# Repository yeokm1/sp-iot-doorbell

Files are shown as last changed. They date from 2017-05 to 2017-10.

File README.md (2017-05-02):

# SP IoT doorbell

An IoT doorbell at Singapore Power's Digital Tech office that will take a picture of a visitor and notify a Slack channel when the button pressed. The operating system used is Arch Linux ARM and the code is in Python 3.

## Pictures and Demo video

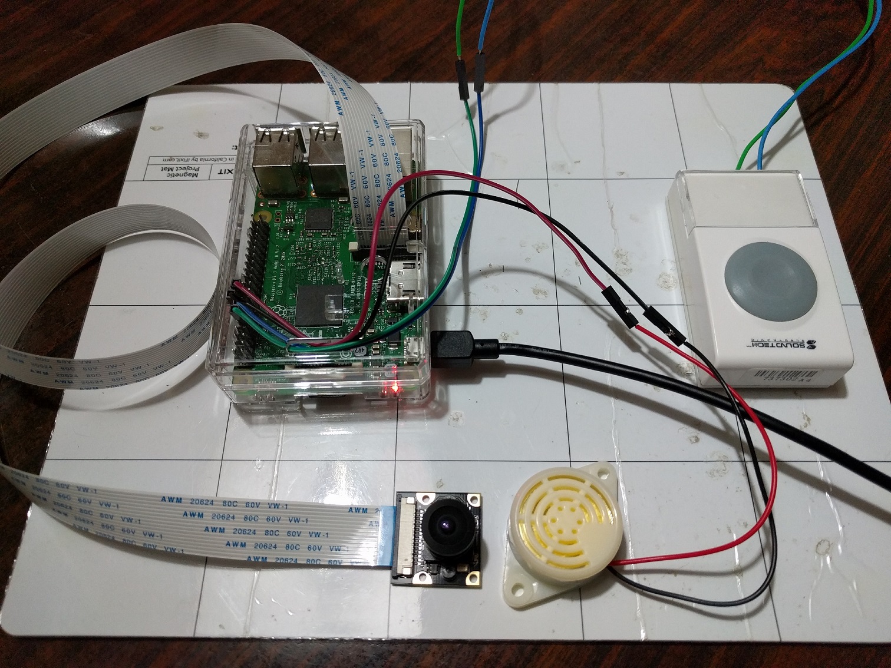
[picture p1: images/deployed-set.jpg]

This is the set that is actually deployed with a proper button and wide-angle camera.

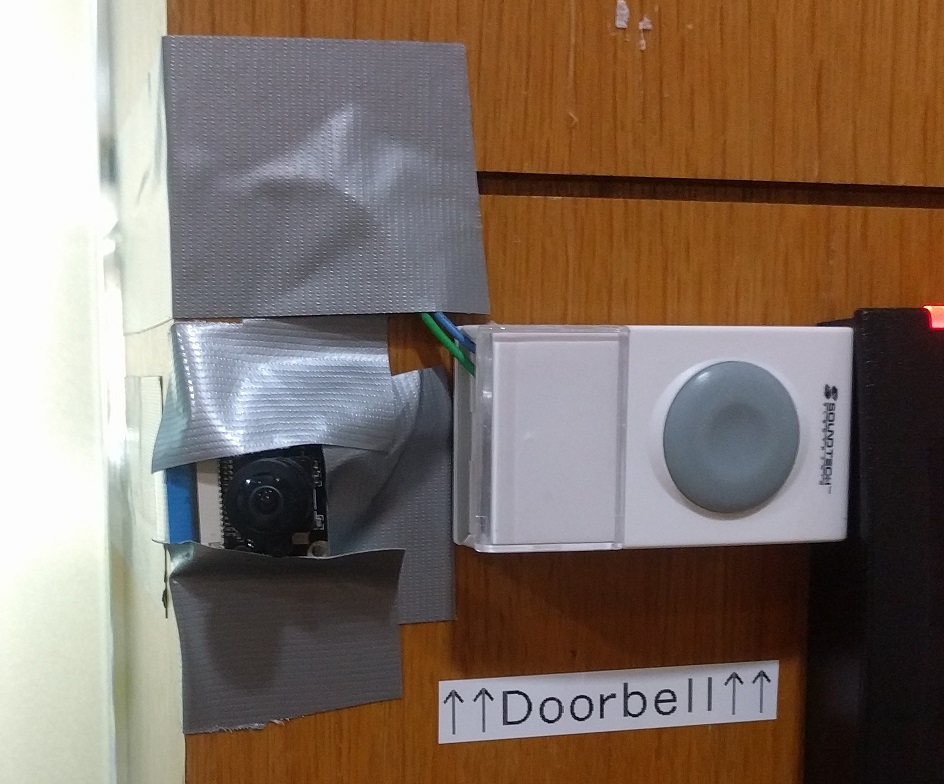
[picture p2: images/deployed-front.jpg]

The camera and button are placed in line to make sure they are associated to be together. Button is modified from an actual doorbell.

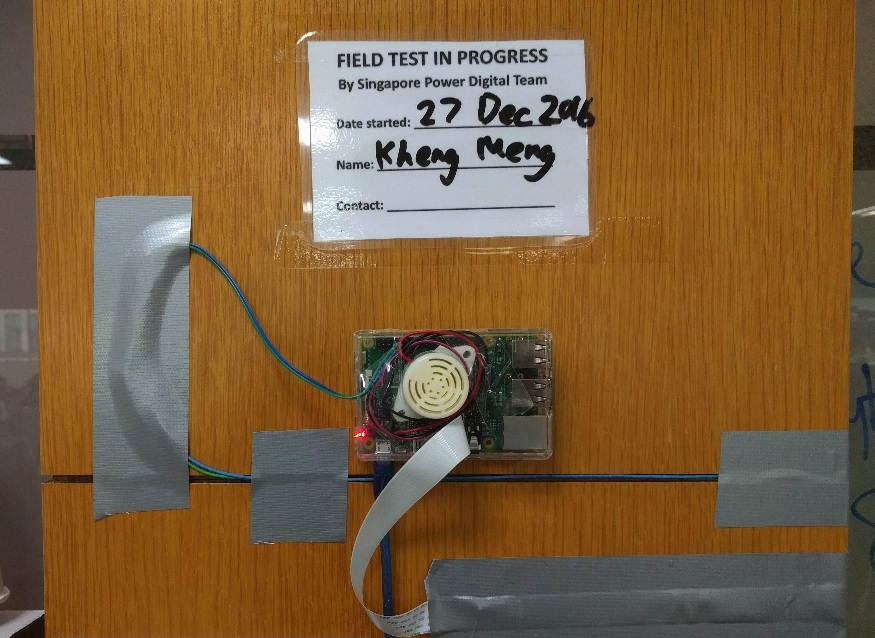
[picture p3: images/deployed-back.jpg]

The camera and button are connected to a Raspberry Pi at the back.

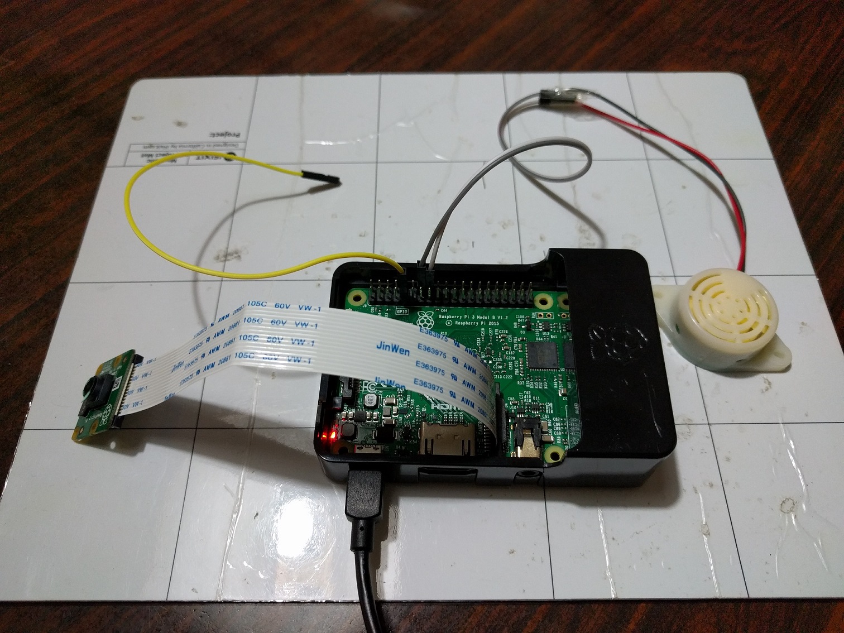
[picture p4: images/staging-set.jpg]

This is used for testing purposes before moving the SD card image to the deployed set. The button is simulated by shorting the pins. Camera is the official [8MP camera board v2](https://sg.element14.com/raspberry-pi/rpi-8mp-camera-board/raspberry-pi-camera-board-v2/dp/2510728).

(http://www.youtube.com/watch?v=MGRNmj3iRuI)

## Behaviour workflow

1. On bootup, the `iot-doorbell.service` in started which in turn launches the `iot-doorbell-startup.sh` shell script. The shell script starts the `bell-camera.py` python code.
2. One beep is output to indicate that the program is started.
3. The program will test connectivity to `http://slack.com` by repeatedly hitting it at a rate of 1 attempt/second beeping each time it does so.
4. If 20 failed attempts has been made, the program will stop trying and output only 1 beep to indicate the failure. It will then continue in just a dumb doorbell mode. If connection is achieved later, the pictures will also be sent.
5. If connectivity to Slack is successful, the program will output 2 beeps and send a boot success message to Slack.
6. Whenever the button is pressed, the program will start a thread to send one text-only message first so the Slack channel can be alerted quickly. The image is then taken and uploaded in a second message which will take slightly longer.
7. I have set the minimum interval between messages sending to be 10 seconds to prevent channel flooding from continuous pressing. The bell however will continue to ring as long as the button is pressed.

## Schematic

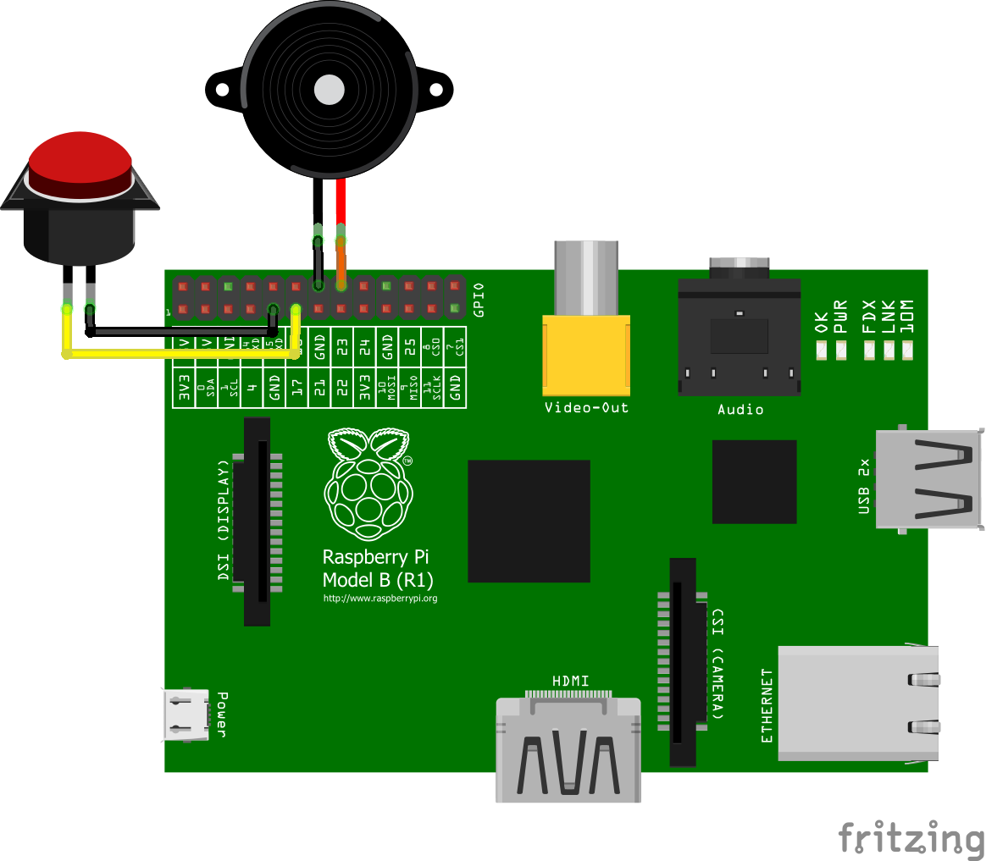
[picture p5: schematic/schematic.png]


A Fritzing drawing indicating the connection between the components to the Raspberry Pi 3. The picture depicted is that of the first Pi B+ which has the exact same pinout as the Pi 3 for the first few pins.

A wide-angle camera is connected to the CSI connector.

## Parts required
1. Raspberry Pi 3
2. 8GB or larger SD card
3. [Piezo Buzzer 3-20VDC Continuous Tone](http://www.sgbotic.com/index.php?dispatch=products.view&product_id=1926)
4. [Raspberry Pi Wide Angle Camera Module](https://www.seeedstudio.com/Raspberry-Pi-Wide-Angle-Camera-Module-p-2774.html)
5. [70cm Camera Flex cable](http://www.sgbotic.com/index.php?dispatch=products.view&product_id=2258)
6. [Raspberry Pi clear case](http://sg.element14.com/multicomp/83-17540/enclosure-raspberry-pi-3-2-b-clear/dp/2674868)
7. 2A USB Power Adapter
8. microUSB cable for power
9. Some random doorbell button
10. USB-TTL cable for configuration

## Setting up the Raspberry Pi from scratch

1) Set up the Arch Linux ARM on an SD card by following the [official instructions](https://archlinuxarm.org/platforms/armv8/broadcom/raspberry-pi-3).

2) Before removing the SD card from the computer, access the `boot` partition. Open `config.txt`. Add the following into the file. First 3 lines enable the camera. Last line enables the console over the UART pins.

```
gpu_mem=128
start_file=start_x.elf
fixup_file=fixup_x.dat
enable_uart=1
```
3) Power on the RPi and convert the file system to read-only if needed by following my [gist](https://gist.github.com/yeokm1/8b0ffc03e622ce011010). You don't have to enable root over SSH as we will disable SSH at the end of this anyway.

4) Connect an Ethernet cable with internet connection. Enter the root account via the USB-UART and run the following commands

```bash
#Install all dependencies
pacman -Syu python python-pip wget base-devel yajl git cronie
pip install requests

#Let alarm user control gpio pins without being root
groupadd -f -r gpio
usermod -G gpio alarm
vi /etc/udev/rules.d/99-gpio.rules

#Add the following to the 99-gpio-rules file
SUBSYSTEM=="bcm2835-gpiomem", KERNEL=="gpiomem", GROUP="gpio", MODE="0660"
SUBSYSTEM=="gpio", KERNEL=="gpiochip*", ACTION=="add", PROGRAM="/bin/sh -c 'chown root:gpio /sys/class/gpio/export /sys/class/gpio/unexport ; chmod 220 /sys/class/gpio/export /sys/class/gpio/unexport'"
SUBSYSTEM=="gpio", KERNEL=="gpio*", ACTION=="add", PROGRAM="/bin/sh -c 'chown root:gpio /sys%p/active_low /sys%p/direction /sys%p/edge /sys%p/value ; chmod 660 /sys%p/active_low /sys%p/direction /sys%p/edge /sys%p/value'"
#end of adding
```
5) Switch over to the alarm user. This user account will be used to run non-privileged stuff including the python program.

```bash
su alarm
cd ~
git clone https://github.com/yeokm1/sp-iot-doorbell.git
cd sp-iot-doorbell

#chmod in case you transfer the file in without executable permissions
chmod +x iot-doorbell-startup.sh
su -c "cp iot-doorbell.service /etc/systemd/system/"

#Install yaourt so as to prepare to install the GPIO package from AUR
cd ~
git clone https://aur.archlinux.org/package-query.git
cd package-query
makepkg -s
su -c "pacman -U package-query-1.8-2-armv7h.pkg.tar.xz"

cd ..

git clone https://aur.archlinux.org/yaourt.git
cd yaourt
makepkg -s
su -c "pacman -U yaourt-1.8.1-1-any.pkg.tar.xz"

yaourt -S python-raspberry-gpio

#1. Enter "1" to install the only package if asked
#2. Give alarm (default "alarm") and root password (default "root") when asked
#3. Do NOT edit PKGBUILD or anything else when they say "Unsupported Package" or similar warnings. Press "N".
#4. Answer Yes to install any requested dependencies or building

#Clear command history
history -cw
exit
```

6) You should be back to the root account.

```bash
#Restart the device every Monday at 0700
crontab -e
00 7   *   *   1    /usr/bin/reboot
systemctl enable cronie.service

#Enable the service so the program will start on boot
systemctl enable iot-doorbell.service

#Disable SSH for security reasons
systemctl disable sshd
```

7) Configure Wifi settings (Optional)

```bash
cp /etc/netctl/examples/wireless-wpa /etc/netctl/.
nano /etc/netctl/wireless-wpa
#Adjust settings to match your network

#This is to test your profile. If you are not using SSH, you should unplug the Ethernet cable now to test.
netctl start wireless-wpa
#Take effect on every boot
netctl enable wireless-wpa
```

8) Change default user passwords

```bash
passwd root

passwd alarm
```

9) Clear command history and reboot

```bash
#Clear command history
history -cw

reboot
```

## References

1. [Check server availability in Python](http://stackoverflow.com/questions/3764291/checking-network-connection)
2. [Post requests in Python](http://stackoverflow.com/questions/37283111/cannot-post-images-to-slack-channel-via-web-hooks-utilizing-python-requests)
3. [Use GPIO without being root](https://arcanesciencelab.wordpress.com/2016/03/31/running-rpi3-applications-that-use-gpio-without-being-root/)

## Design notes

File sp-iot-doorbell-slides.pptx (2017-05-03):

## SP Office Gadget: IoT Doorbell

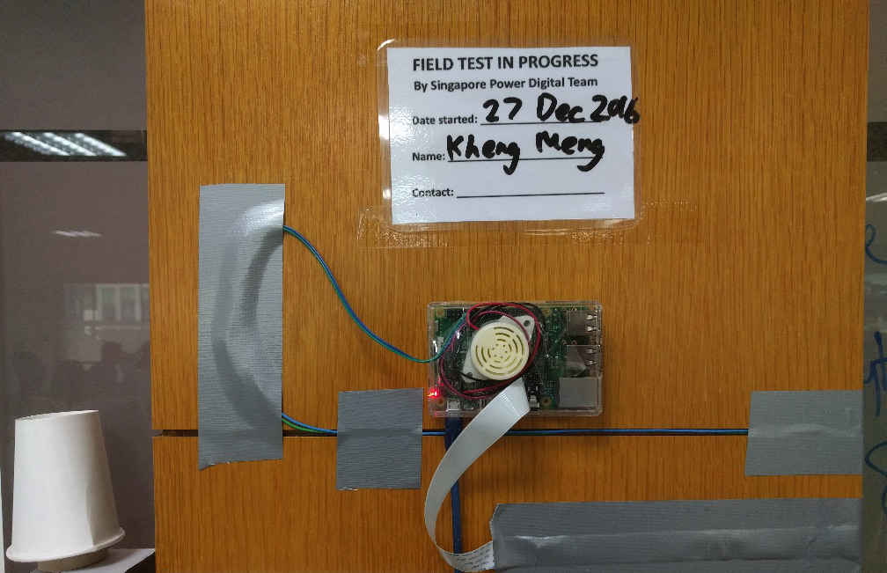
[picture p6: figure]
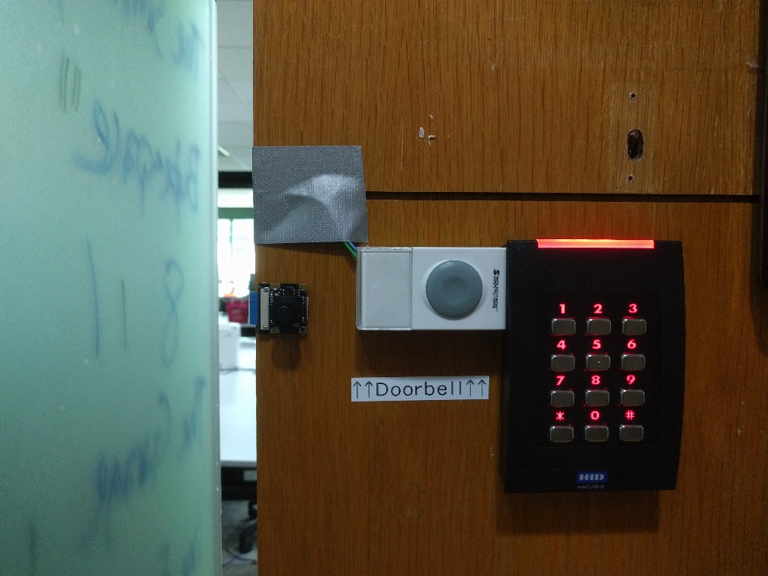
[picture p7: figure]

By: Yeo Kheng Meng (yeokm1@gmail.com)
https://github.com/yeokm1/sp-iot-doorbell

Hackware v3.0 (3 May 2017)
SP Digital Tech Talk (29 Dec 2016)

## Problem?

- My office needs a doorbell
- Solution: An overengineered IoT doorbell

## Solution Outline

1. Rings when button is pressed
2. Informs Slack channel via Wifi connection
3. Takes photo and uploads to Slack
4. File system resilience against improper shutdown

## Demo video

- https://www.youtube.com/watch?v=MGRNmj3iRuI

## MVP Dev Set

- Raspberry Pi 3
- 8MP RPi camera v2
  - Sony IMX219
  - Connected via Camera Serial Interface connector
- 3V-20V DC Continuous Buzzer
- Wire simulated as a button


## The button

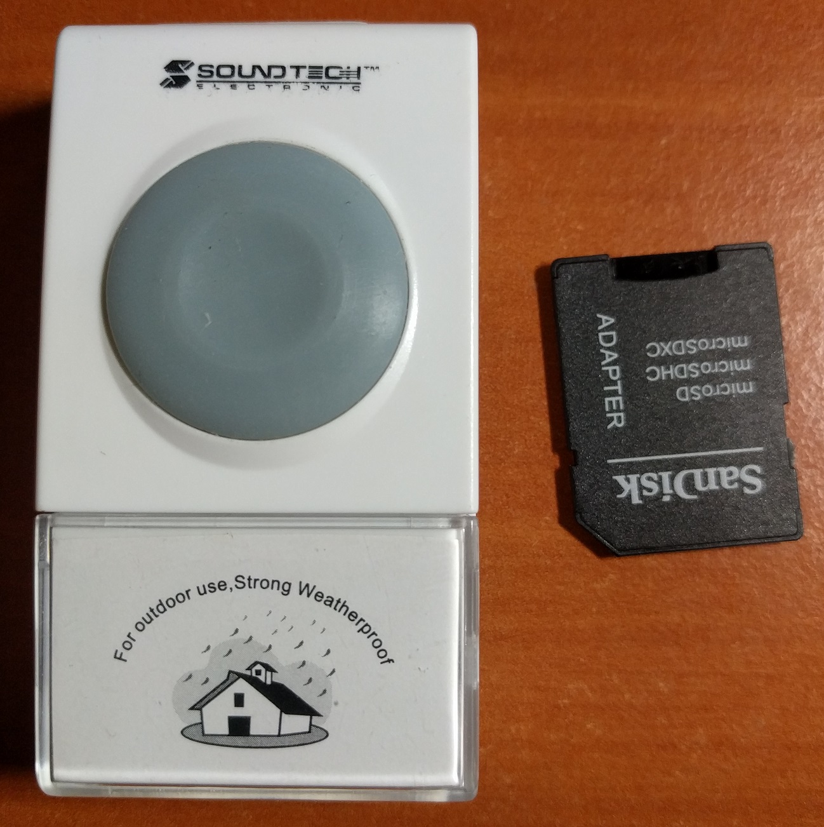
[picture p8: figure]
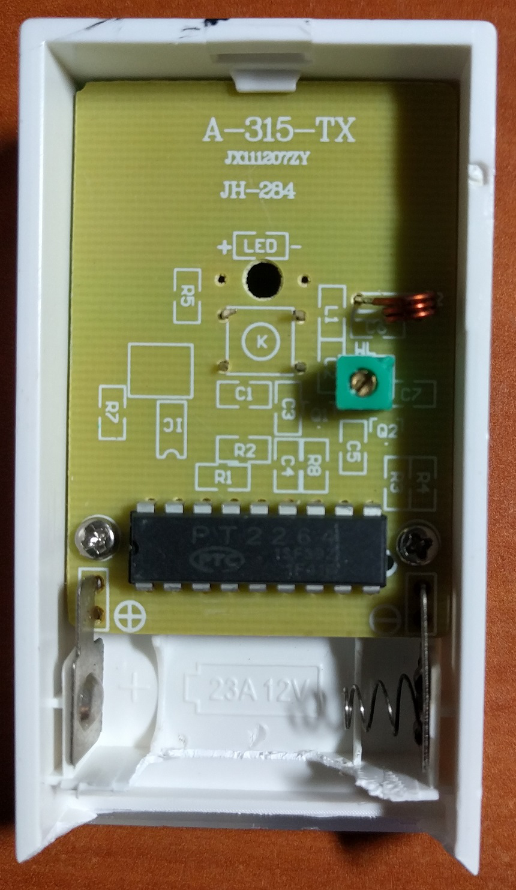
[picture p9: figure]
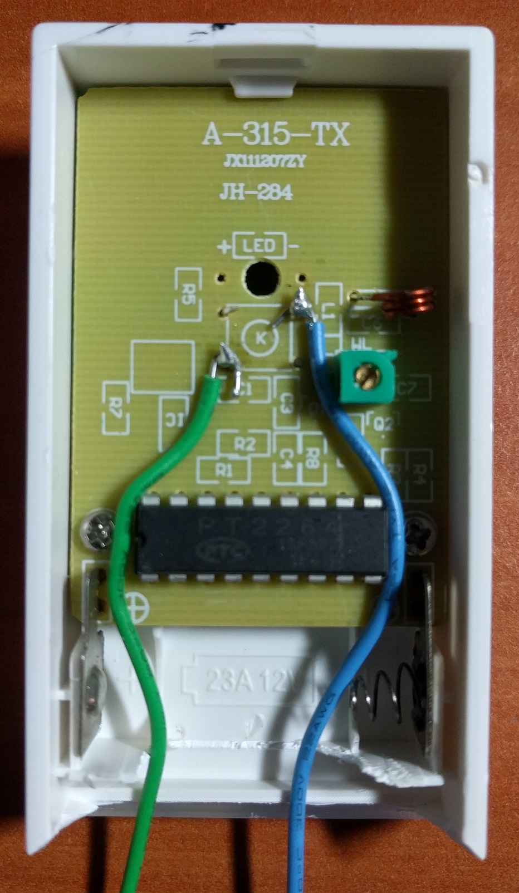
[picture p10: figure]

## Camera

- 5MP 160° Horizontal Wide Angle (Fisheye lens)
  - Usual 72°
- 70cm flex cable
  - Usual 10cm
- https://www.seeedstudio.com/Raspberry-Pi-Wide-Angle-Camera-Module-p-2774.html

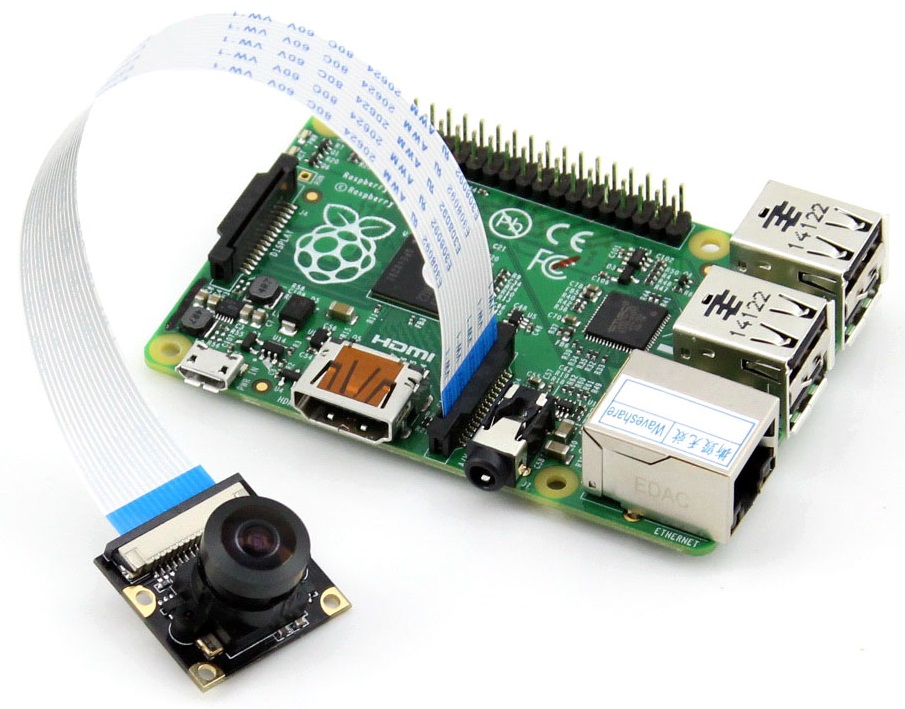
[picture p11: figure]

## Raspistill’s camera settings

- /opt/vc/bin/raspistill -ISO 800 -ss 40000 -q 30 -rot 270 -t 1 -w 640 -h 480 -o /tmp/iot-doorbell-visitor.jpg
- 30% JPEG quality
- 270° rotation
- 1 millisecond picture-taking delay
  - Default 5 seconds
  - 0 value does not work
- 640x480 resolution
- -> ~100KB file size
- ISO 800
- 40ms shutter speed

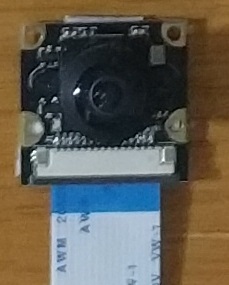
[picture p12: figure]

## Slack integration

- Create Slack bot and get token
- https://sp-digital.slack.com/apps/A0F7YS25R-bots
- Post Message API: https://api.slack.com/methods/chat.postMessage
- File Upload API: https://api.slack.com/methods/files.upload
- Slack Python SDK Bug: Only allows file upload from user, not bot
- https://github.com/slackapi/python-slackclient/issues/102

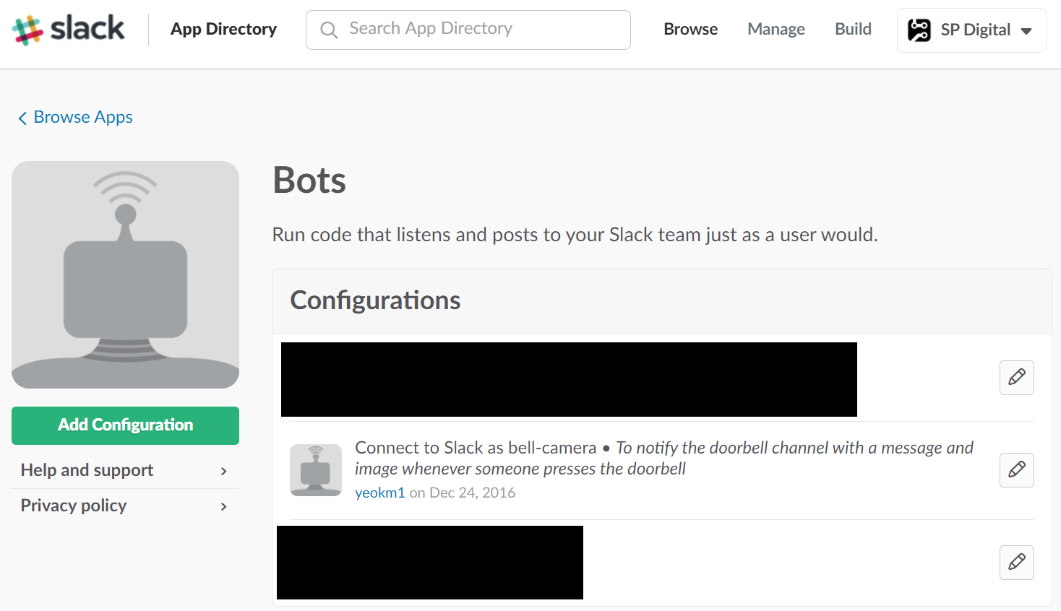
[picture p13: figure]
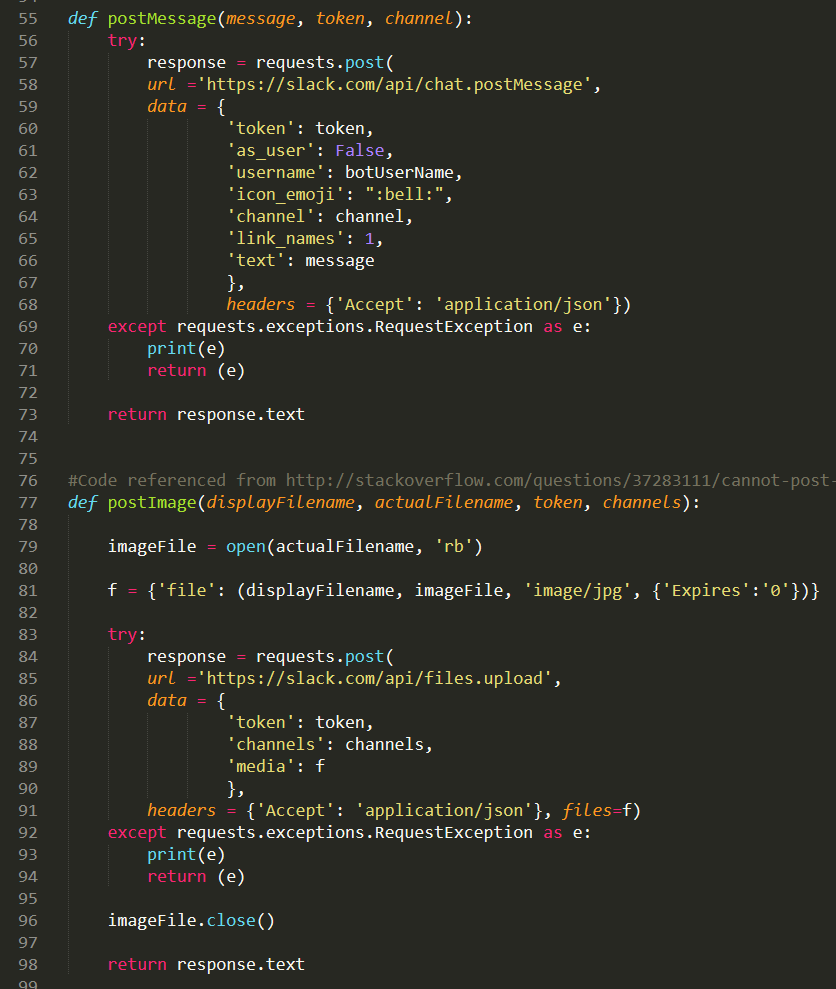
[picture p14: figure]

## Operating System

- Arch Linux ARM
  - My FAVOURITE for personal Raspberry Pi projects
  - https://archlinuxarm.org/platforms/armv8/broadcom/raspberry-pi-3
- Minimal packages OOTB
  - OOTB: Package Manager (pacman), networking, shell, text editor, SSH
  - No Git, wget, GUI, Python, GCC
- Cutting edge kernel and package releases
  - Node.js
  - Python3 as default python

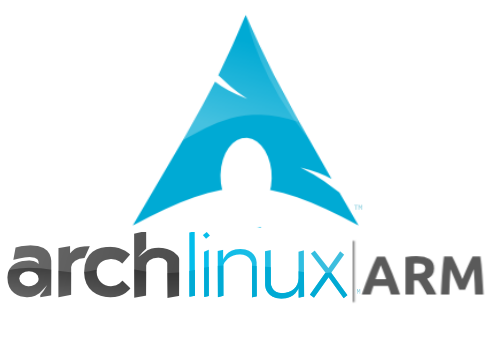
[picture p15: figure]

## Console access via USB-UART

Access console without SSH
SSH disabled for security
Add to /boot/config.txt
enable_uart=1
Refer to:
https://engineers.sg/video/raspberry-pi-3-uart-bluetooth-issues--609
Hackware (30 March 2016)

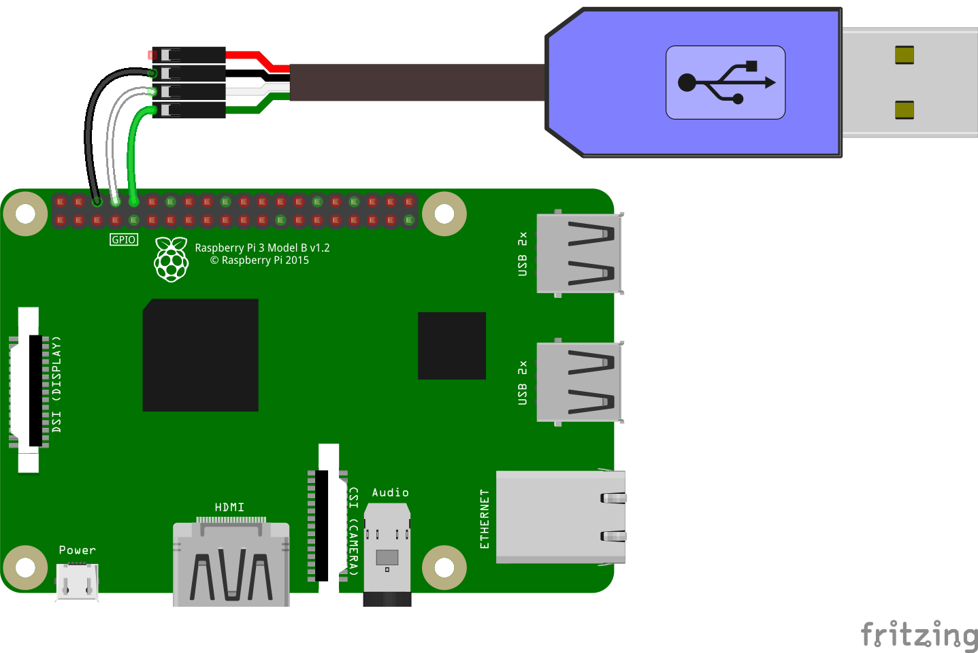
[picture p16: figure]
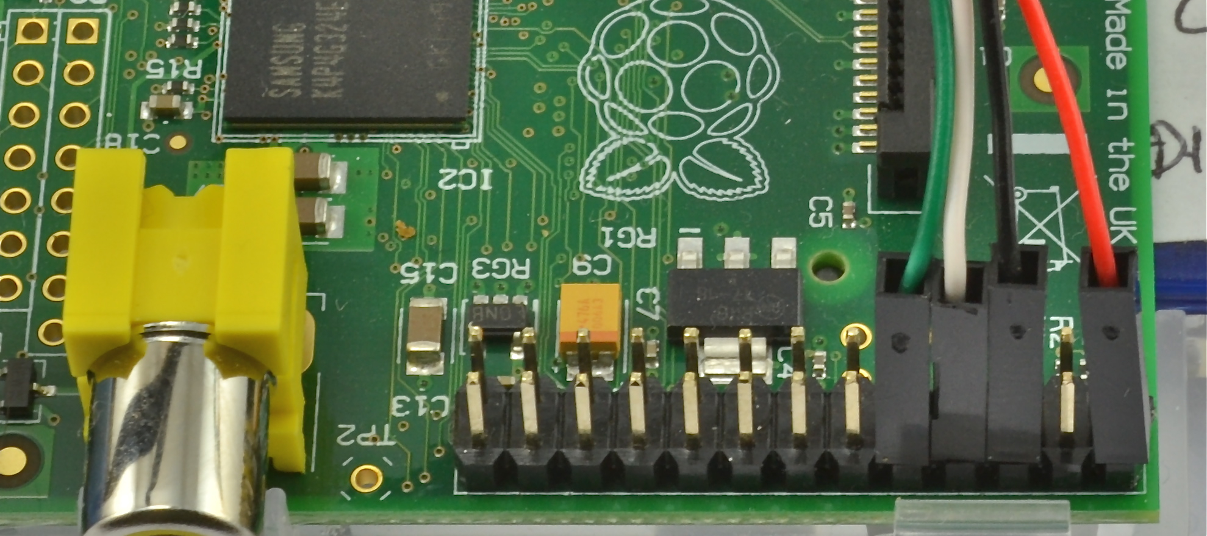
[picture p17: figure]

## Read-only file system for embedded systems

- Prevent file-system corruption during improper shutdown
- Increase SD card/flash lifespan

## Read-only file system options

- ----------------/etc/fstab------------------------
/dev/mmcblk0p1 /boot vfat defaults,ro,errors=remount-ro 0 0
tmpfs /var/tmp tmpfs nodev,nosuid 0 0
tmpfs /var/log tmpfs nodev,nosuid 0 0
- tmpfs: RAM drive used for temp and log directories
- ----------------/boot/cmdline.txt------------------------
- Set “ro” option for root directory
- ----------------/etc/systemd/journald.conf-----------
- Storage=none

https://gist.github.com/yeokm1/8b0ffc03e622ce011010

## Questions

By: Yeo Kheng Meng (yeokm1@gmail.com)
https://github.com/yeokm1/sp-iot-doorbell

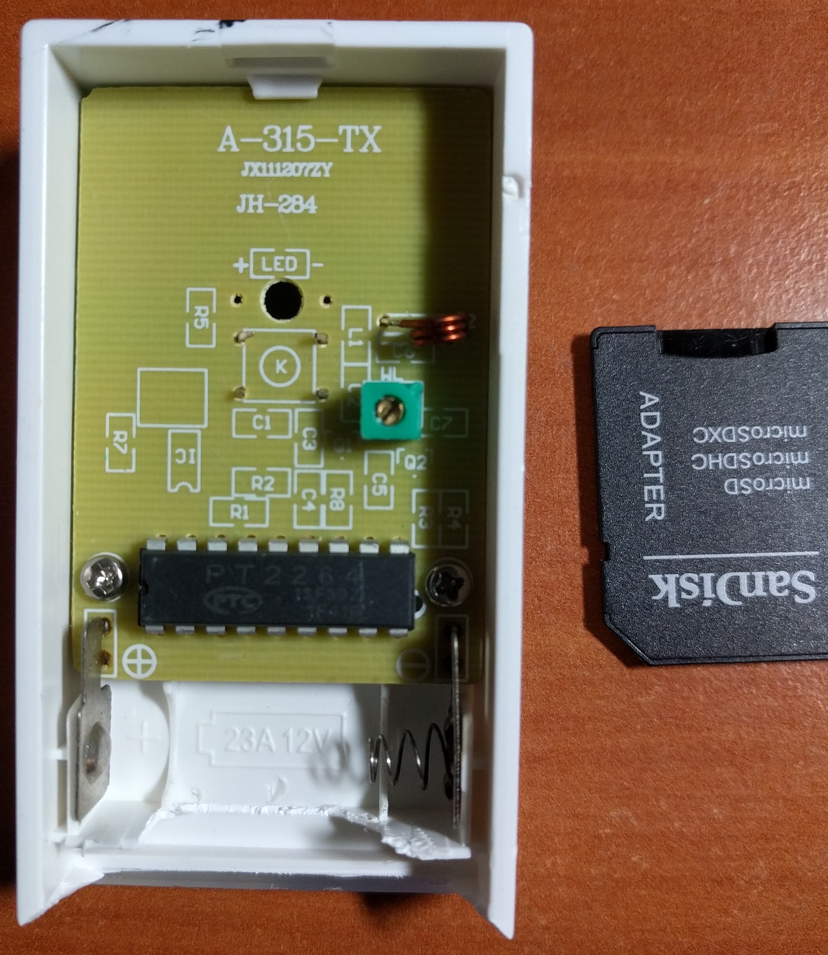
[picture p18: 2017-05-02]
images/bell-opened.jpg

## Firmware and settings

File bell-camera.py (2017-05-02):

import time
import requests
import os
import RPi.GPIO as GPIO
import _thread
import socket

from time import sleep

# Put your slack token here
#slack_token = os.environ["SLACK_API_TOKEN"]
slack_token = "xxxx"

channelID = "#doorbell"
botUserName = "bell-camera"

pathToImage = "/tmp/iot-doorbell-visitor.jpg"

#Rotate 270 as camera is placed at angle, 30% quality and 640x480 resolution to reduce file size
takePictureCommand = "/opt/vc/bin/raspistill -ISO 800 -ss 40000 -q 30 -rot 270 -t 1 -w 640 -h 480 -o " + pathToImage

buttonPin = 17
buzzerPin = 23

minimumSendSlackInterval = 10 #seconds
referenceServer = "slack.com"
maxInitialConnectionRetries = 20

isInternetActive = False

isSendingThreadActive = False
lastSentTime = time.time()


#Referenced from http://stackoverflow.com/questions/20913411/test-if-an-internet-connection-is-present-in-python
def isInternetON(referenceServer):
    try:
        host = socket.gethostbyname(referenceServer)
        s = socket.create_connection((host, 80), 2)
        return True
    except :
        return False

def takePicture():
    os.system(takePictureCommand)

def generateNewDisplayFilename():
    timestr = time.strftime("%Y-%m-%d-%H%M%S")
    displayFilename = timestr + ".jpg"
    return displayFilename

def sendMessage(message):
    postMessage(message, slack_token, channelID)

def postMessage(message, token, channel):
    try:
        response = requests.post(
        url ='https://slack.com/api/chat.postMessage',
        data = {
                'token': token,
                'as_user': False,
                'username': botUserName,
                'icon_emoji': ":bell:",
                'channel': channel,
                'link_names': 1,
                'text': message
                },
                headers = {'Accept': 'application/json'})
    except requests.exceptions.RequestException as e:
        print(e)
        return (e)

    return response.text


#Code referenced from http://stackoverflow.com/questions/37283111/cannot-post-images-to-slack-channel-via-web-hooks-utilizing-python-requests
def postImage(displayFilename, actualFilename, token, channels):

    imageFile = open(actualFilename, 'rb')

    f = {'file': (displayFilename, imageFile, 'image/jpg', {'Expires':'0'})}

    try:
        response = requests.post(
        url ='https://slack.com/api/files.upload',
        data = {
                'token': token,
                'channels': channels,
                'media': f
                },
        headers = {'Accept': 'application/json'}, files=f)
    except requests.exceptions.RequestException as e:
        print(e)
        return (e)

    imageFile.close()

    return response.text


def sendToSlackThread():
    global isSendingThreadActive

    if(isSendingThreadActive):
        return

    isSendingThreadActive = True

    print ("Taking picture")
    takePicture()

    print ("Sending first quick message")
    sendMessage("Visitor is @here!")

    print ("Uploading image")
    postImage(generateNewDisplayFilename(), pathToImage, slack_token, channelID)

    print ("Image upload attempt completed")

    isSendingThreadActive = False


GPIO.setmode(GPIO.BCM)
GPIO.setup(buttonPin, GPIO.IN, pull_up_down=GPIO.PUD_UP)
GPIO.setup(buzzerPin, GPIO.OUT)


# One buzz to indicate program start
print ("Output initial buzzes")
GPIO.output(buzzerPin, 1)
sleep(0.3)
GPIO.output(buzzerPin, 0)
sleep(0.3)

#Loop until network connection is obtained, buzz a short while for each attempt
for x in range(0, maxInitialConnectionRetries):
    print("Trying to hit reference server " + referenceServer + " attempt " + str(x))
    GPIO.output(buzzerPin, 1)
    sleep(0.01)
    GPIO.output(buzzerPin, 0)

    if(isInternetON(referenceServer)):
        isInternetActive = True
        break

    sleep(1)

if(isInternetActive):
    print("Sending initial test message")
    sendMessage("Test message after boot")

    # Two buzzes to indicate test message was just sent
    GPIO.output(buzzerPin, 1)
    sleep(0.3)
    GPIO.output(buzzerPin, 0)
    sleep(0.3)
    GPIO.output(buzzerPin, 1)
    sleep(0.3)
    GPIO.output(buzzerPin, 0)
else:
    GPIO.output(buzzerPin, 1)
    sleep(0.3)
    GPIO.output(buzzerPin, 0)


print("Program active")

while True:
    sleep(0.1)

    buttonInput = GPIO.input(buttonPin)

    #Logic is inverted as the button is pull up
    if(buttonInput):
        GPIO.output(buzzerPin, 0)
    else:
        GPIO.output(buzzerPin, 1)

        currentTime = time.time()

        if(not isSendingThreadActive and (currentTime - lastSentTime) >= minimumSendSlackInterval):
            lastSentTime = currentTime
            _thread.start_new_thread(sendToSlackThread,())
